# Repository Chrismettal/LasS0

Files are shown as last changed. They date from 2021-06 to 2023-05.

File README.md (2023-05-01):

# LasS0 <!-- omit in toc -->

# Contents <!-- omit in toc -->

- [Buying](#buying)
- [What is this?](#what-is-this)
- [Usage](#usage)
  - [Jumpers:](#jumpers)
- [Firmware](#firmware)
- [Performance](#performance)
  - [New AVR version](#new-avr-version)
    - [0-5V DC pulses, 10Hz, 10ms pulse length](#0-5v-dc-pulses-10hz-10ms-pulse-length)
    - [Shortest stable input pulse - 150ns](#shortest-stable-input-pulse---150ns)
    - [Rise time / delay 100µs](#rise-time--delay-100µs)
    - [5\_10\_i\_r firmware example](#5_10_i_r-firmware-example)
  - [Old S8050 / FET version](#old-s8050--fet-version)
    - [0-5V DC pulses, 50Hz, 5ms pulse length](#0-5v-dc-pulses-50hz-5ms-pulse-length)
    - [Rise time 33µs, Fall time 1µs](#rise-time-33µs-fall-time-1µs)
    - [Switch on delay 66µs](#switch-on-delay-66µs)
    - [Switch off delay 5µs](#switch-off-delay-5µs)
    - [TCRCT5000 with "normal" non inverted configuration](#tcrct5000-with-normal-non-inverted-configuration)
    - [TCRCT5000 with "inverted" configuration](#tcrct5000-with-inverted-configuration)
- [3D printing](#3d-printing)

# Buying

Some leftover boards are stocked at Tindie. More can be manufactured if there is demand:



**If you like my work please consider [supporting my caffeine addiction](https://github.com/Chrismettal#donations)!**

# What is this?

This is a logic level impulse to S0 converter/interface board. It is used to convert 5v logic level impulses to an S0 compatible format to use sensors like the TCRT5000 reflective optical sensor in existing smart home systems, that usually use 12v or 24v levels for digital inputs. This can be used to read out old school electrical meters as well as modern smart meters that only offer optical IR impulses or a spinning disc to "display" the current power usage.

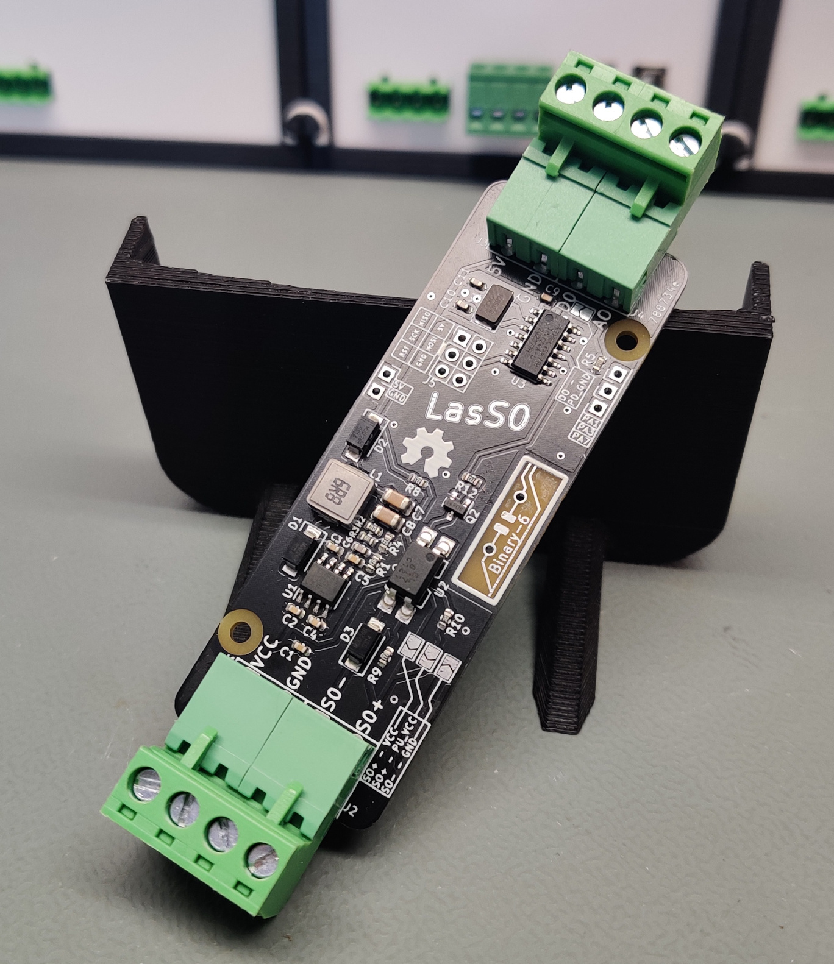
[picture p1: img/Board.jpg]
BoardReal


There are 'two versions' of the board included. LasS0_FET uses a FET input stage. The included gerbers are NOT tested and probably won't be. The initial NPN input stage version however was ordered and tested working.
The other, more recent version uses an AVR microcontroller as the input stage, specifically providing pulse extension and pulse division between the input and the S0 output. This was neccessary for me since my electricity meter outputs 10,000 imp/kWh with only a pulselength of about 7ms, which my smart home controller could not read. It required pulses of at least 15ms to reliably detect every pulse. The AVR counts a set number of input pulses and outputs a fixed output pulse once enough inputs have been counted. In my case I divide 10:1 and output a 30ms pulse after every 10 input pulses, changing the total resolution of my specific meter to 1,000 imp/kwh.

The AVR board additionaly breaks out all unused portpins to pinheaders as well as the AO screw terminal so you could theoretically read out the analog value of a TCRT5000 as well.

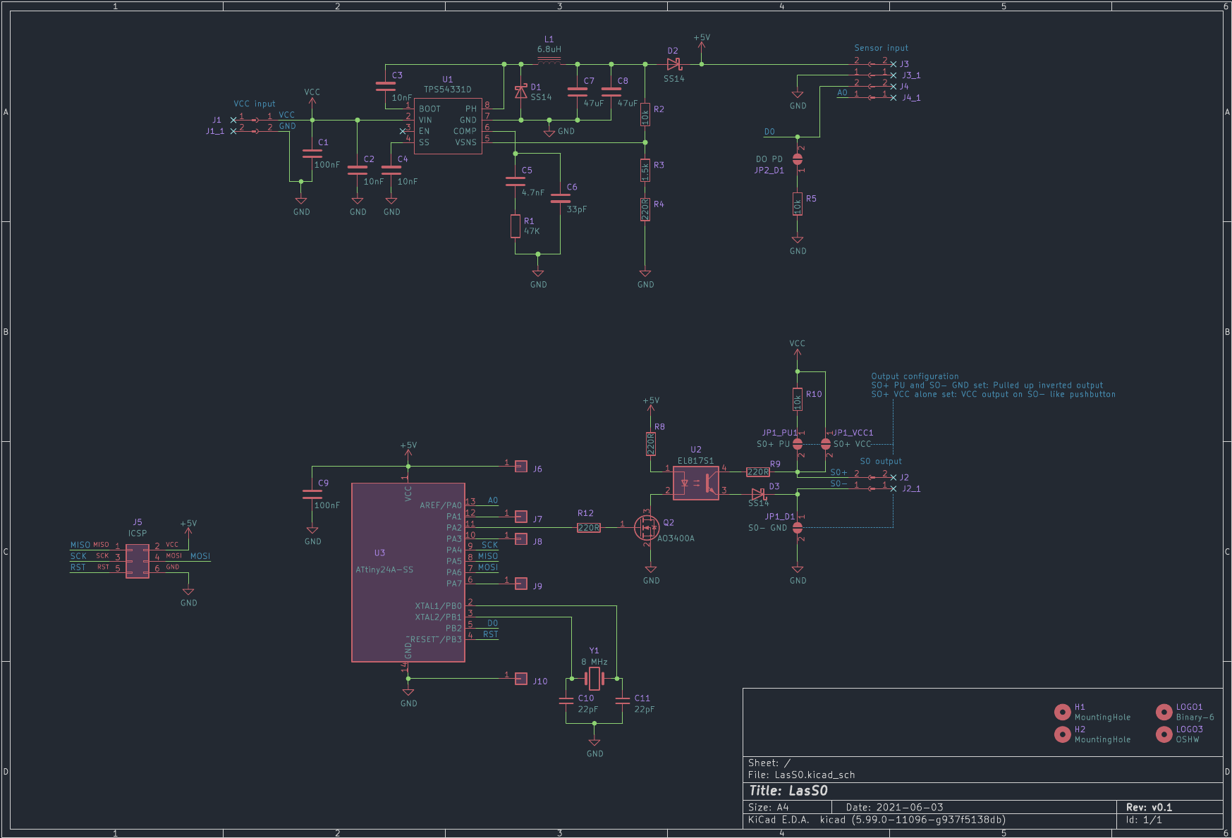
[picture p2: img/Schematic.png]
Schematic


# Usage

The device needs to be powered through `J1` with 12-24v.

One of the upper jumpers needs to be set to choose between `Direct` and `Inverted` which would invert the output fully. If no jumper is set you won't get any output. If both jumpers are set you are going to have a bad time.

A 5v logic level impulse input such as the output of a TCRT5000 can be connected to `J3/J4` at `D0`, which is then output to `J2` as an `S0` compatible open collector signal through the optocoupler.

## Jumpers:

The following jumpers need to be configured to your usecase. Without setting anything, you will get an open S0 output without any pullup/downs on the inputs or outputs.

- `S0+ - VCC` - connects `S0+` to `VCC`, allowing VCC pulses to be output on `S0-`
- `S0+ - PU_VCC` - connects `S0+` to `VCC` via a 10K pullup.
- `S0- - GND` - connects `S0-` to `GND`,  can be used with `S0+ - PU_VCC` to have 24 V logic pulses on `S0+`, which is how I use it for Loxone inputs
- `D0-PD_GND` - connects a 10K pulldown to the D0 input. The AVR only has included pullups on the input port so if your application needs a pulldown it can be enabled on the board. Pullups can be enabled in firmware.

Additionally `PA1`, `PA3`, `PA7` as well as `5V` and `GND` are broken out to pin headers, the `ICSP` port is fully exposed to pin headers, and `PA0` is exposed to the `A0` screw terminal, enabling analog inputs as well.

# Firmware

To translate any type of input pulse to any type of output pulse an Attiny24a is used. The firmware is done in C but built in PlatformIO. The project can be found in the `firmware/Platformio` folder. To compile and upload, you will need to choose one of the build environments as `default` will compile and upload all build configurations one after the other.

If you don't wanna compile yourself, there are several prebuild binaries for different configurations of input and output pulses. Find them in the `firmware/builds` directory.
This directory contains  .elf and .hex files for every environment.

The naming structure for the environments is as follows:

`tinyWW_XXX_Y_Z`

- `W` = Divider ratio
- `X` = Output pulse length
- `Y` = `r` for rising edge input, `f` for falling edge input
- `Z` = `i` for inverted output, `n` for non-inverted output

So:
- `tiny10_30_n_r` generates a `30 ms` `positive` output pulse for every `10` `rising edges` on the input
- `tiny5_250_i_f` generates a `250ms` `negative` output pulse for every `5` `falling edges` on the input

The firmware is uploaded via `ICSP`.

# Performance

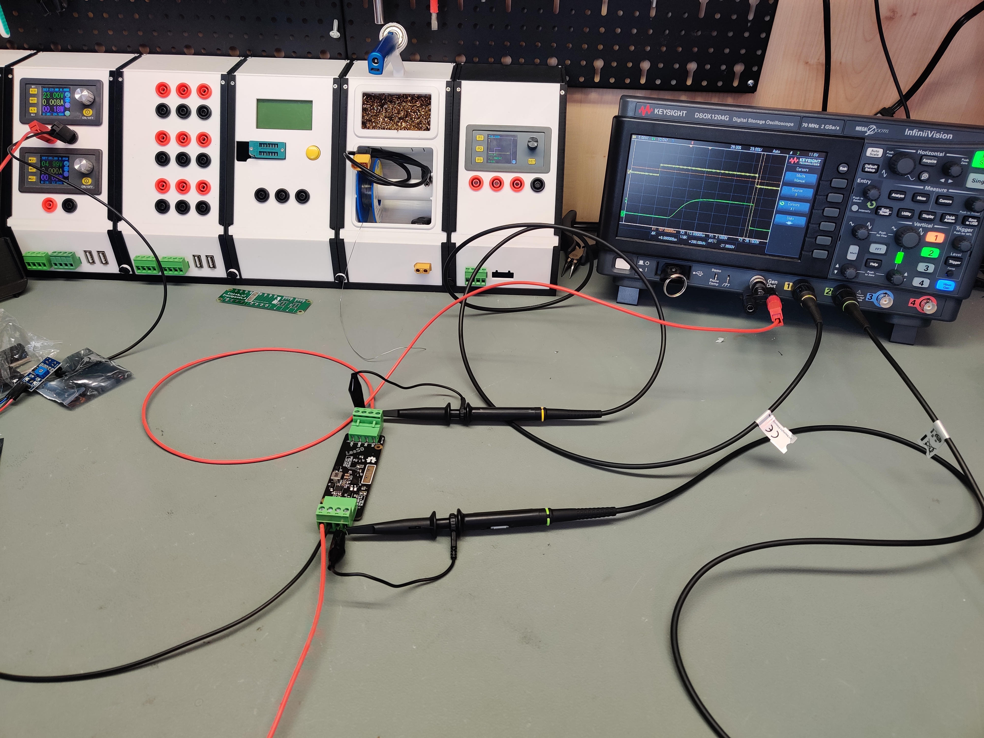
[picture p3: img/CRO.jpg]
MeasurementMethod


The device was tested, on a 23 V supply with 5 V test pulses from a function gen as well as the TCRT5000.
## New AVR version

This version uses the high input impedance of the ATTINY inputs, reducing required input current significantly, not loading your input sensor at all. The following measurements / demonstrations were done with the `AVR` board, PCB version 788734e, with the `S0+ - PU_VCC` and `S0- - GND` jumpers set, setting a pullup to `SO+` and connecting `S0-` to ground. `Channel 1` is the function gen output, `Channel 2` is measuring the pulled up `S0+`. 

The firmware version used is 1_10_n_r, outputting a 10ms non-inverted output pulse for every rising edge on the input.

### 0-5V DC pulses, 10Hz, 10ms pulse length

10ms input pulses being translated to 10ms output pulses, just shifting levels.

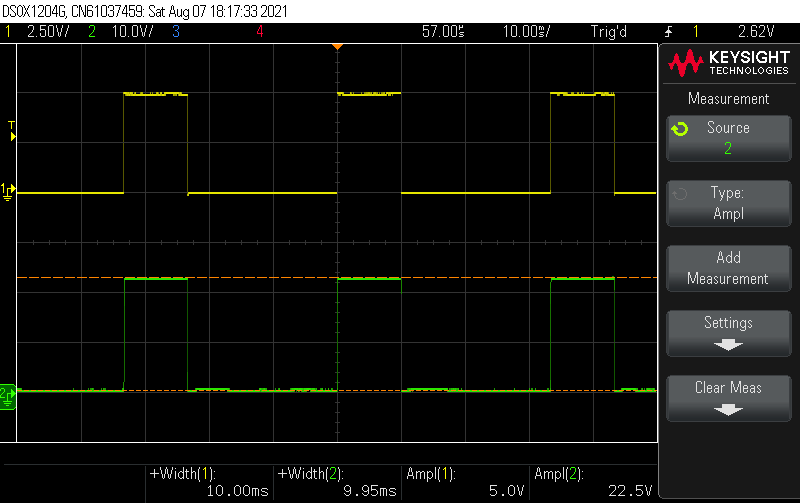
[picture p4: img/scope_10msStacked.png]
10msStacked


### Shortest stable input pulse - 150ns

The shortest input pulse that is stable to detect is about 150ns long at 5V. The device still outputs a 10ms output pulse.

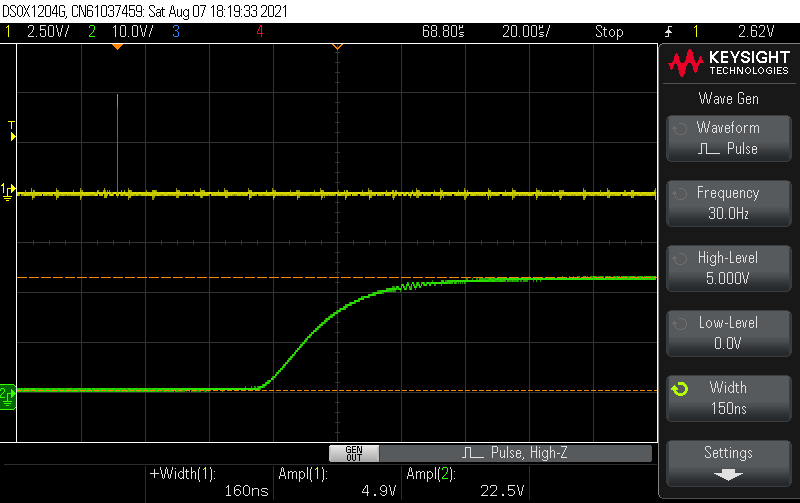
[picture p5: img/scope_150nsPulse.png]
150nsPulse


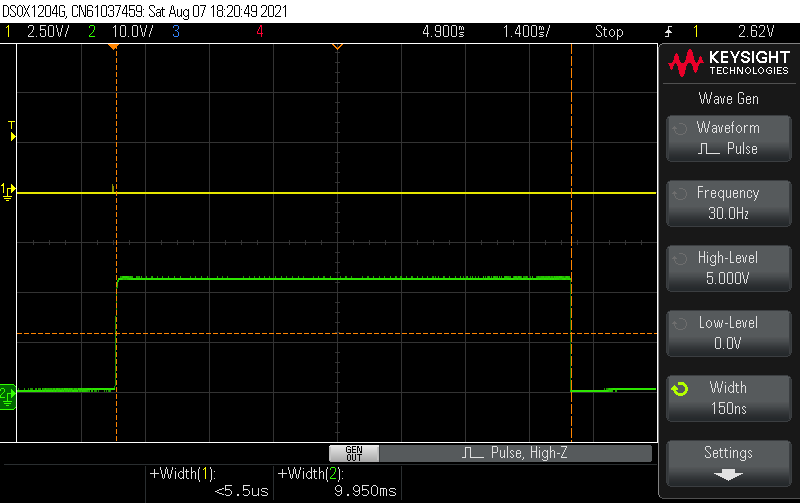
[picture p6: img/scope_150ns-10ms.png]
150ns10ms


### Rise time / delay 100µs

Looking only at the switch on time the device needs about 100µs to fully switch on the output after detecting a rising edge on the input.

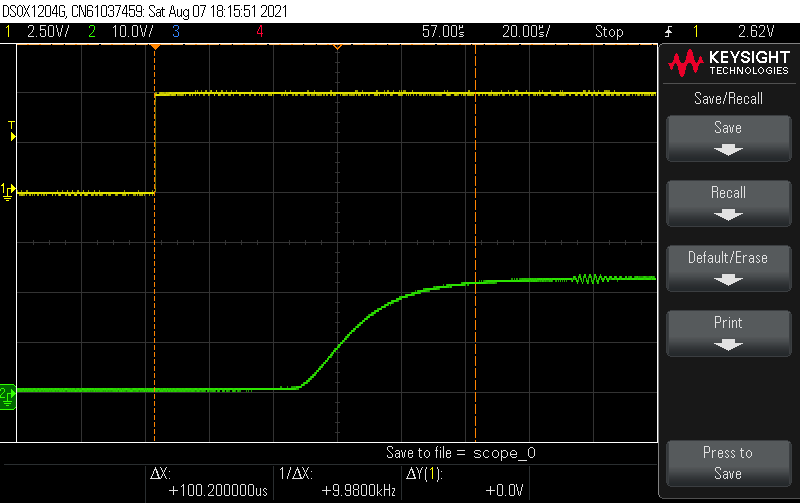
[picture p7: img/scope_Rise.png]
Rise100


### 5_10_i_r firmware example

The following screenshot is a demonstration of the 5_10_i_r firmware, outputting a 10ms inverted output pulse for every 5 edges on the input.

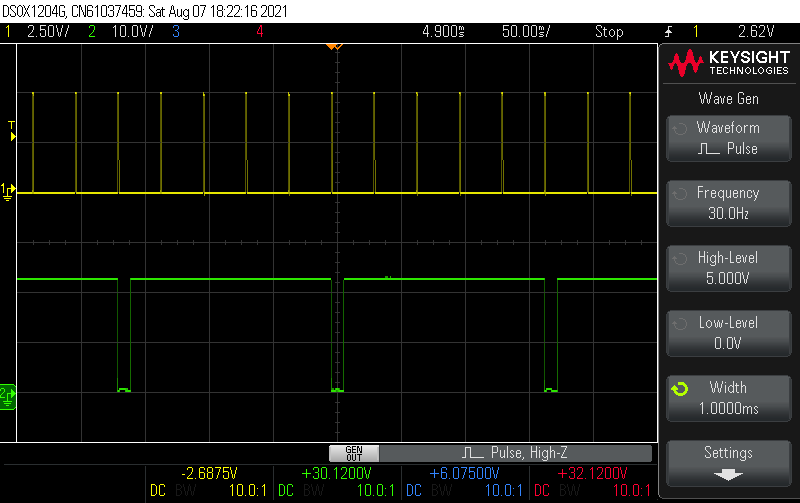
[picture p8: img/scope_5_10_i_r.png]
5_10_i_r


## Old S8050 / FET version

The version that was tested needs around 6mA of current on the DO input to drive the input stage. My TCRT5000 module is only able to deliver about 1mA somehow so the channel 1 voltage with the TCRT5000 drops significantly but the output is still fully driven. Currently ordering some new TCRT5000 to see why the comparator can only drive such low currents. 

The same measurements have been done with the FET version using AO34000A MOSFETs, removing the high input current but otherwise providing almost identical outputs (mostly limited by the output optocoupler, which explains the similar results).

The following measurements / demonstrations were done with the S8050 input stage, PCB revision 38b7723, with the S0 pullup jumpers set:

### 0-5V DC pulses, 50Hz, 5ms pulse length

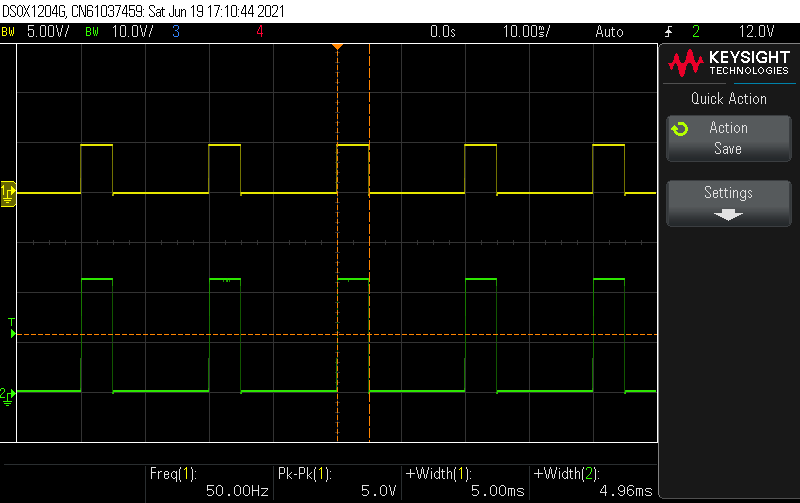
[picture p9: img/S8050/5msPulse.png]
5msPulse


### Rise time 33µs, Fall time 1µs

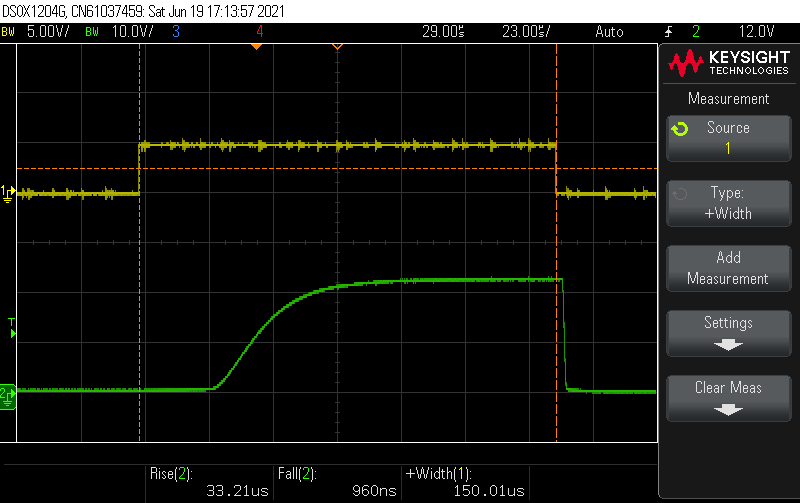
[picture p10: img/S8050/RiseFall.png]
RiseFall


### Switch on delay 66µs

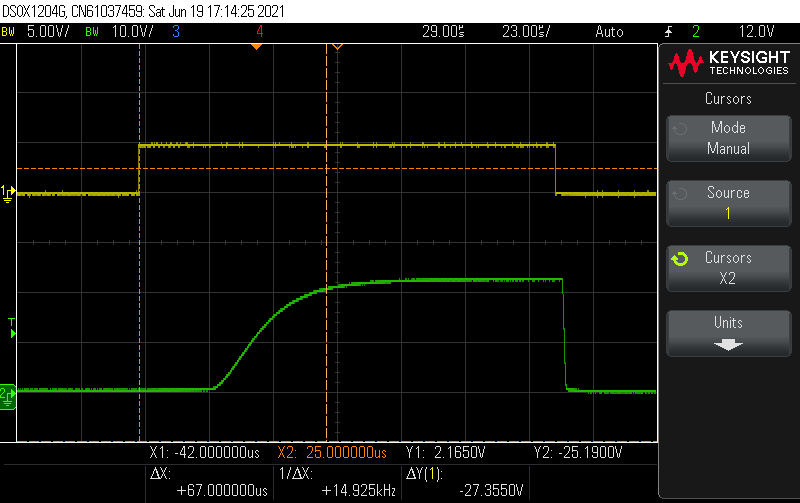
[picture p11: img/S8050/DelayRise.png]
DelayRise


### Switch off delay 5µs

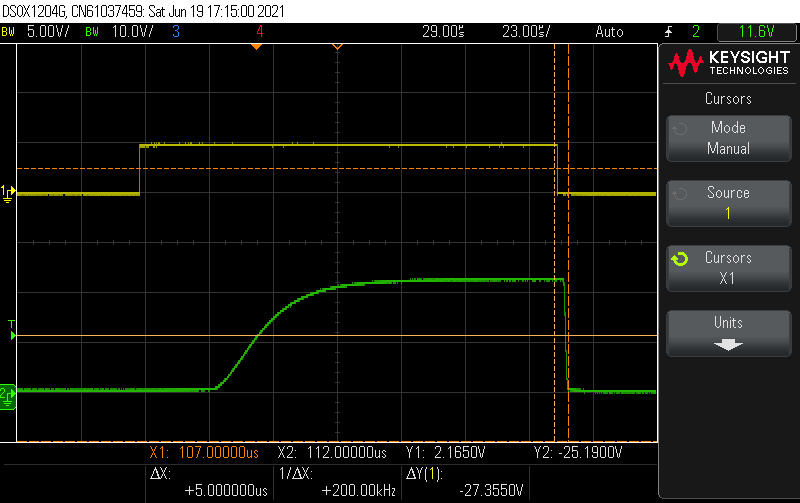
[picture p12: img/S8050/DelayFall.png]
DelayFall


### TCRCT5000 with "normal" non inverted configuration

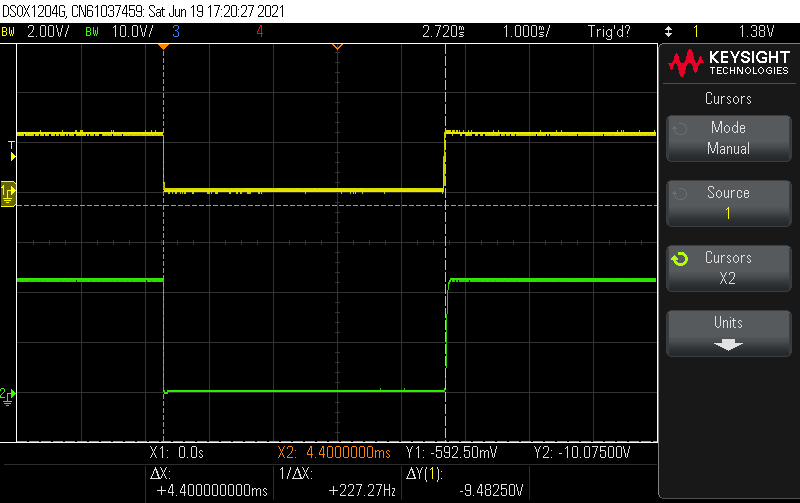
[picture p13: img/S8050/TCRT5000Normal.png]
Normal


### TCRCT5000 with "inverted" configuration

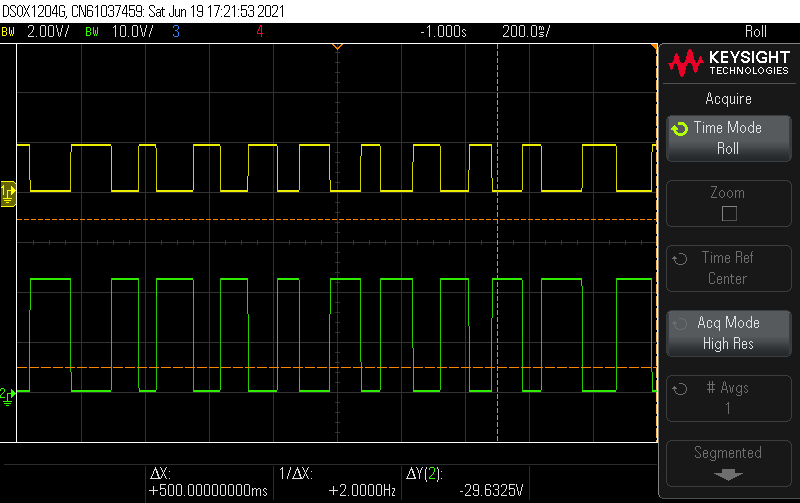
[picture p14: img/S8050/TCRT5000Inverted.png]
Inverted


# 3D printing

Considering this is meant to go inside your electrical cabinet it is best printed in PC or ABS and not PLA.

There is a 3D printable DIN rail case for the LasS0 PCB itself, as well as a readhead to attach a TCRT5000 module to EMH eHZ readers (which is what I am using this whole project for).

The case incorporates DIN rail clamps, remixed from a cable clamp by mdkendall, [check it out here!](https://www.thingiverse.com/thing:2613804).

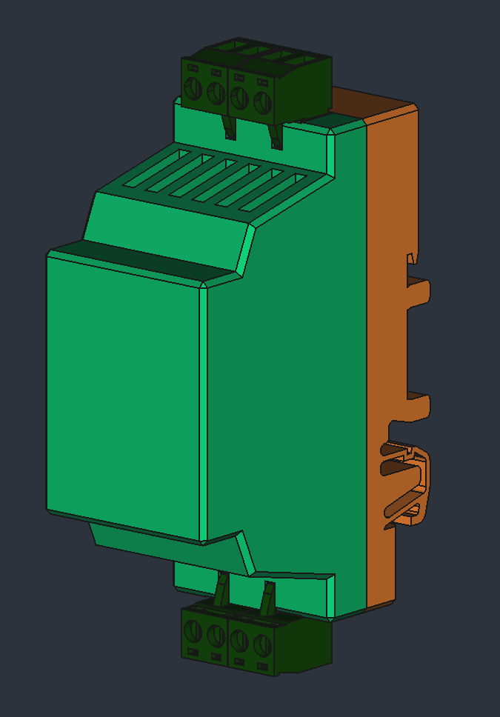
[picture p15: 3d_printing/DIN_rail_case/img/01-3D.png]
3DCase


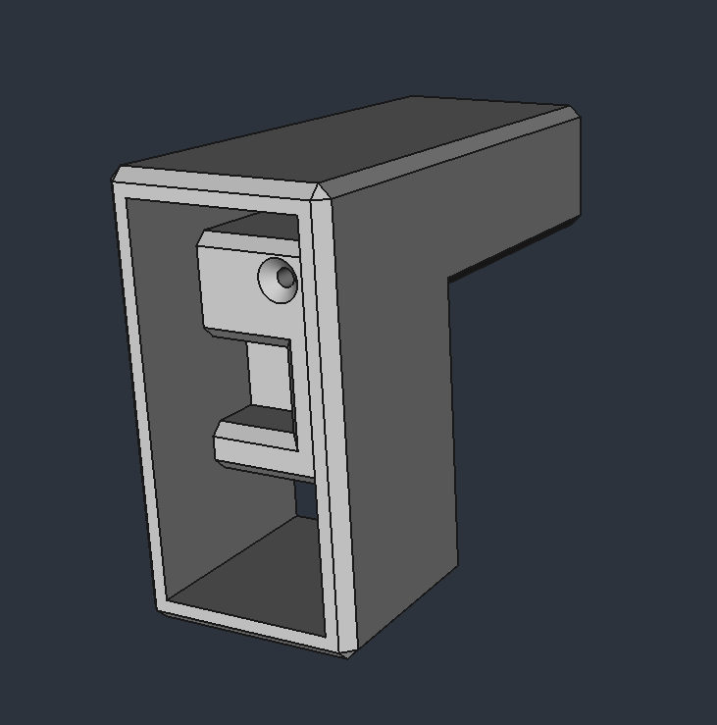
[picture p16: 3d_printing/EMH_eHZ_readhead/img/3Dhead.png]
3DHead


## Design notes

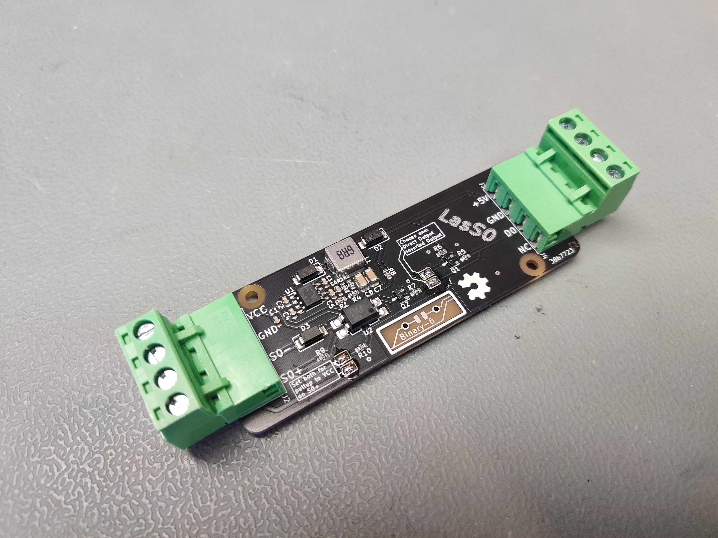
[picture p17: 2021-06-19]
img/S8050/Board.jpg

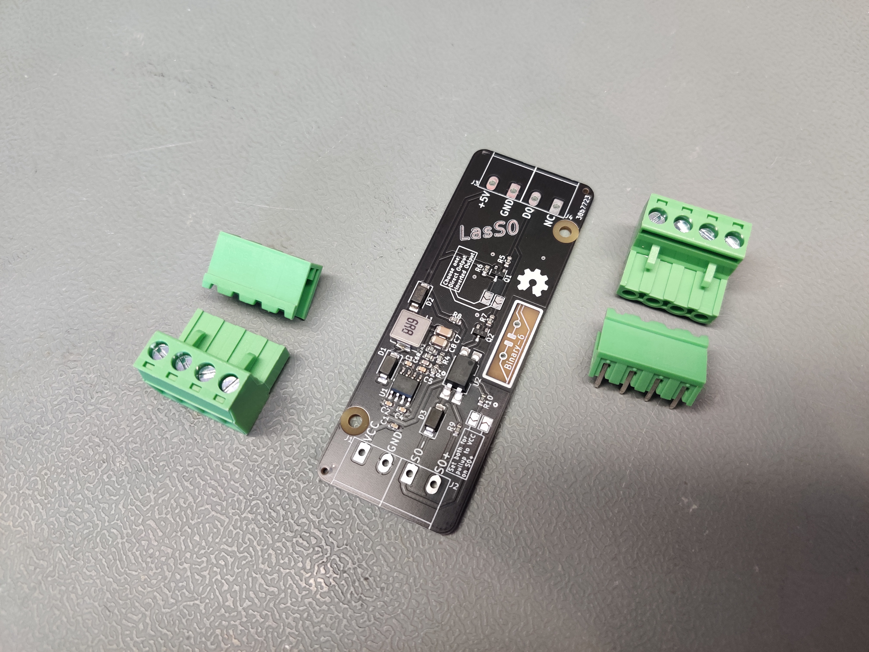
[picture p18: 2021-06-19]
img/S8050/BoardKit.jpg

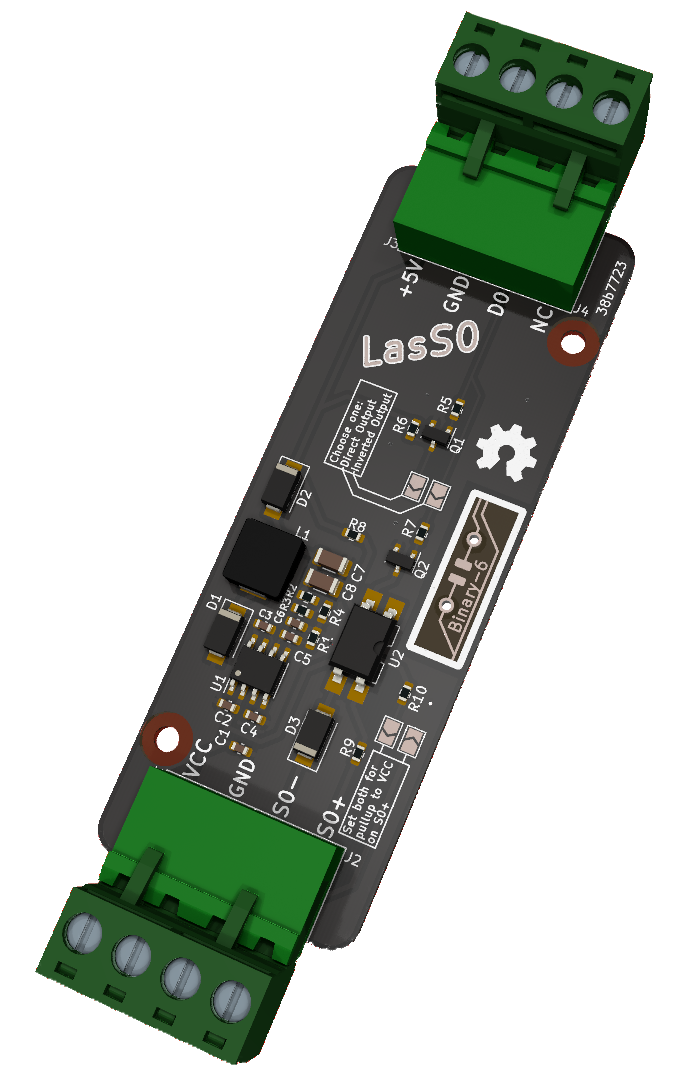
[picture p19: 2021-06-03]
img/S8050/Nice.png

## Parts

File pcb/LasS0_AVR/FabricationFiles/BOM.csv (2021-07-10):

Comment | Designator | Footprint | LCSC
100nF | C1,C9 | Capacitor_SMD:C_0603_1608Metric | C14663
22pF | C10,C11 | Capacitor_SMD:C_0603_1608Metric | C1653
10nF | C2,C3,C4 | Capacitor_SMD:C_0603_1608Metric | C57112
4.7nF | C5 | Capacitor_SMD:C_0603_1608Metric | C53987
33pF | C6 | Capacitor_SMD:C_0603_1608Metric | C1663
47uF | C7,C8 | Capacitor_SMD:C_1206_3216Metric | C96123
SS14 | D1,D2,D3 | Diode_SMD:D_SMA | C2480
CiKe2PinSock | J1,J2,J3,J4 | MeineBib:Cixi_Kefa_Elec_KF2EDGR-5.08-2P | C8383
6.8uH | L1 | MeineBib:Sunltech_SLO0630H | C207841
AO3400A | Q2 | Package_TO_SOT_SMD:SOT-23 | C693097
47K | R1 | Resistor_SMD:R_0603_1608Metric | C25819
10k | R2,R5,R10 | Resistor_SMD:R_0603_1608Metric | C25804
1.5k | R3 | Resistor_SMD:R_0603_1608Metric | C22843
220R | R4,R8,R9,R12 | Resistor_SMD:R_0603_1608Metric | C22962
TPS54331D | U1 | Package_SO:SOIC-8_3.9x4.9mm_P1.27mm | C9865
EL817S1 | U2 | Package_DIP:SMDIP-4_W9.53mm | C106900
ATtiny24A-SS | U3 | Package_SO:SOIC-14_3.9x8.7mm_P1.27mm | C14909
8 MHz | Y1 | Crystal:Crystal_SMD_5032-2Pin_5.0x3.2mm | C115962

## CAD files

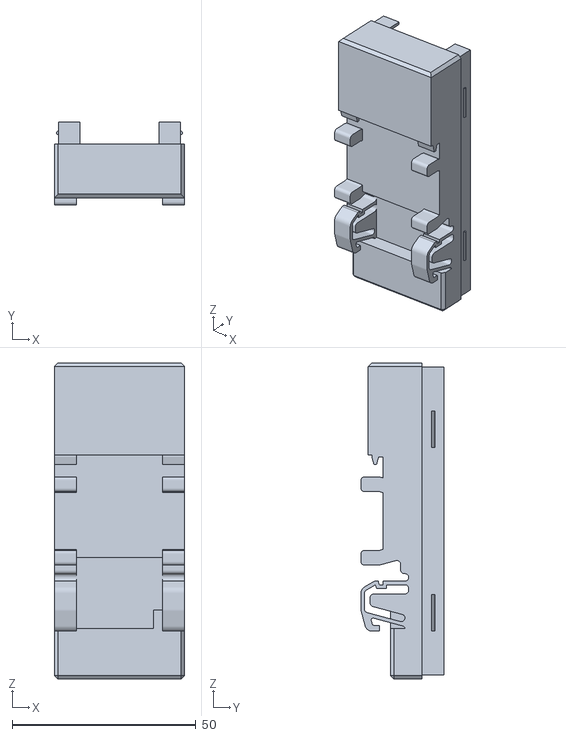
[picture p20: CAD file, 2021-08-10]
3d_printing/DIN_rail_case/3d/LasS0-Lower.stl
35.5 x 22.6 x 86.0

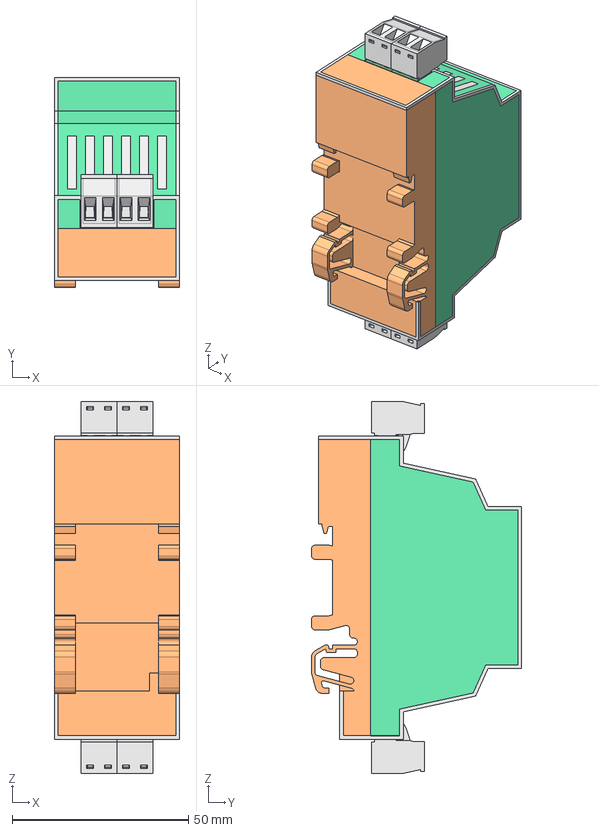
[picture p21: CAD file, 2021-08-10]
3d_printing/DIN_rail_case/source/LasS0.FCStd
35.5 x 59.5 x 105.4 mm
LoxBody
Upper
Lower

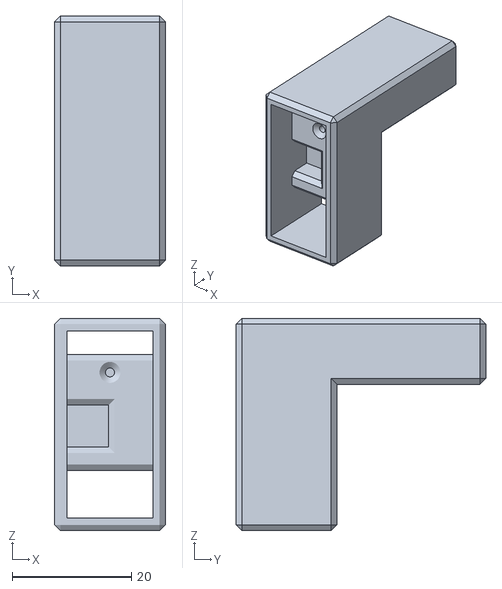
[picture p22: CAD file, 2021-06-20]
3d_printing/EMH_eHZ_readhead/3d/EMH_eHZ_readhead-PartBody.stl
18.7 x 42.0 x 35.7

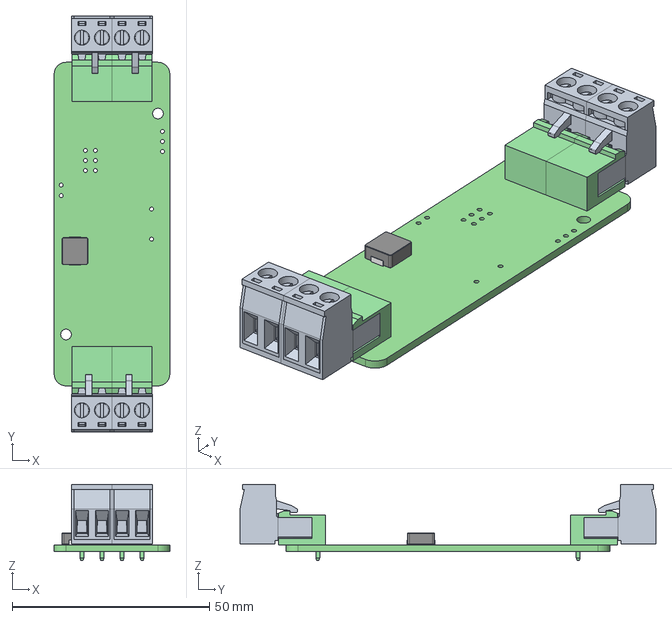
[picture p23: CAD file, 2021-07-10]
pcb/LasS0_AVR/3D/LasS0.step
29.3 x 105.4 x 19.3 mm

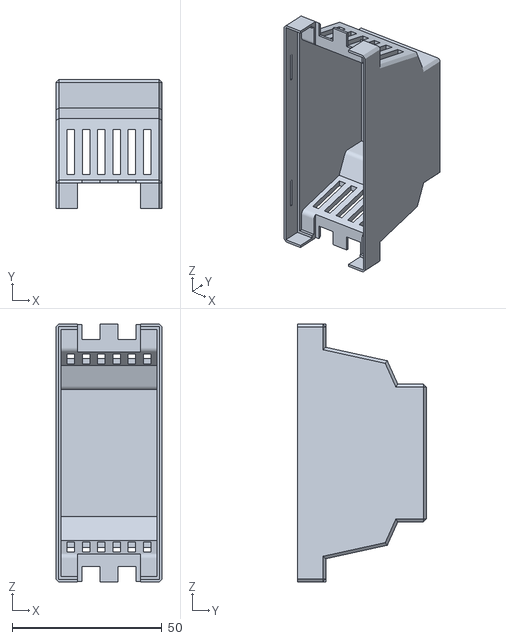
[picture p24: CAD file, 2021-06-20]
3d_printing/DIN_rail_case/3d/LasS0-Upper.stl
35.5 x 42.8 x 86.0

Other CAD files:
3d_printing/EMH_eHZ_readhead/source/EMH_eHZ_readhead.FCStd

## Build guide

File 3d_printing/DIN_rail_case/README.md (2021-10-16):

Autodeploy

It's time for change

Behold, for once again, change is upon us!

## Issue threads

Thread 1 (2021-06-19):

6mA driving current for DO input seems to high for some sensors

Chrismettal, 2021-06-19:
On the 5V DO input side LasS0 needs around 6mA driving current to switch die S8050s, which at least one of my TCRT5000 modules can't provide. Will try switching the input stage to AO3400A MOSFETS instead of NPN transistors to raise input impedance.

Chrismettal, 2021-06-20:
Swapped out the S8050 input stage for AO3400A MOSFETs which greatly raised input impedance. TCRT5000 sensors no longer cry when driving LasS0.

I would not want to leave the input stage without a pulldown for FETs, but since the TCRT5000 modules already use pullups on their output, a fixed pulldown would not be viable, so the PCB update will get optional pullups and downs on the input stage.

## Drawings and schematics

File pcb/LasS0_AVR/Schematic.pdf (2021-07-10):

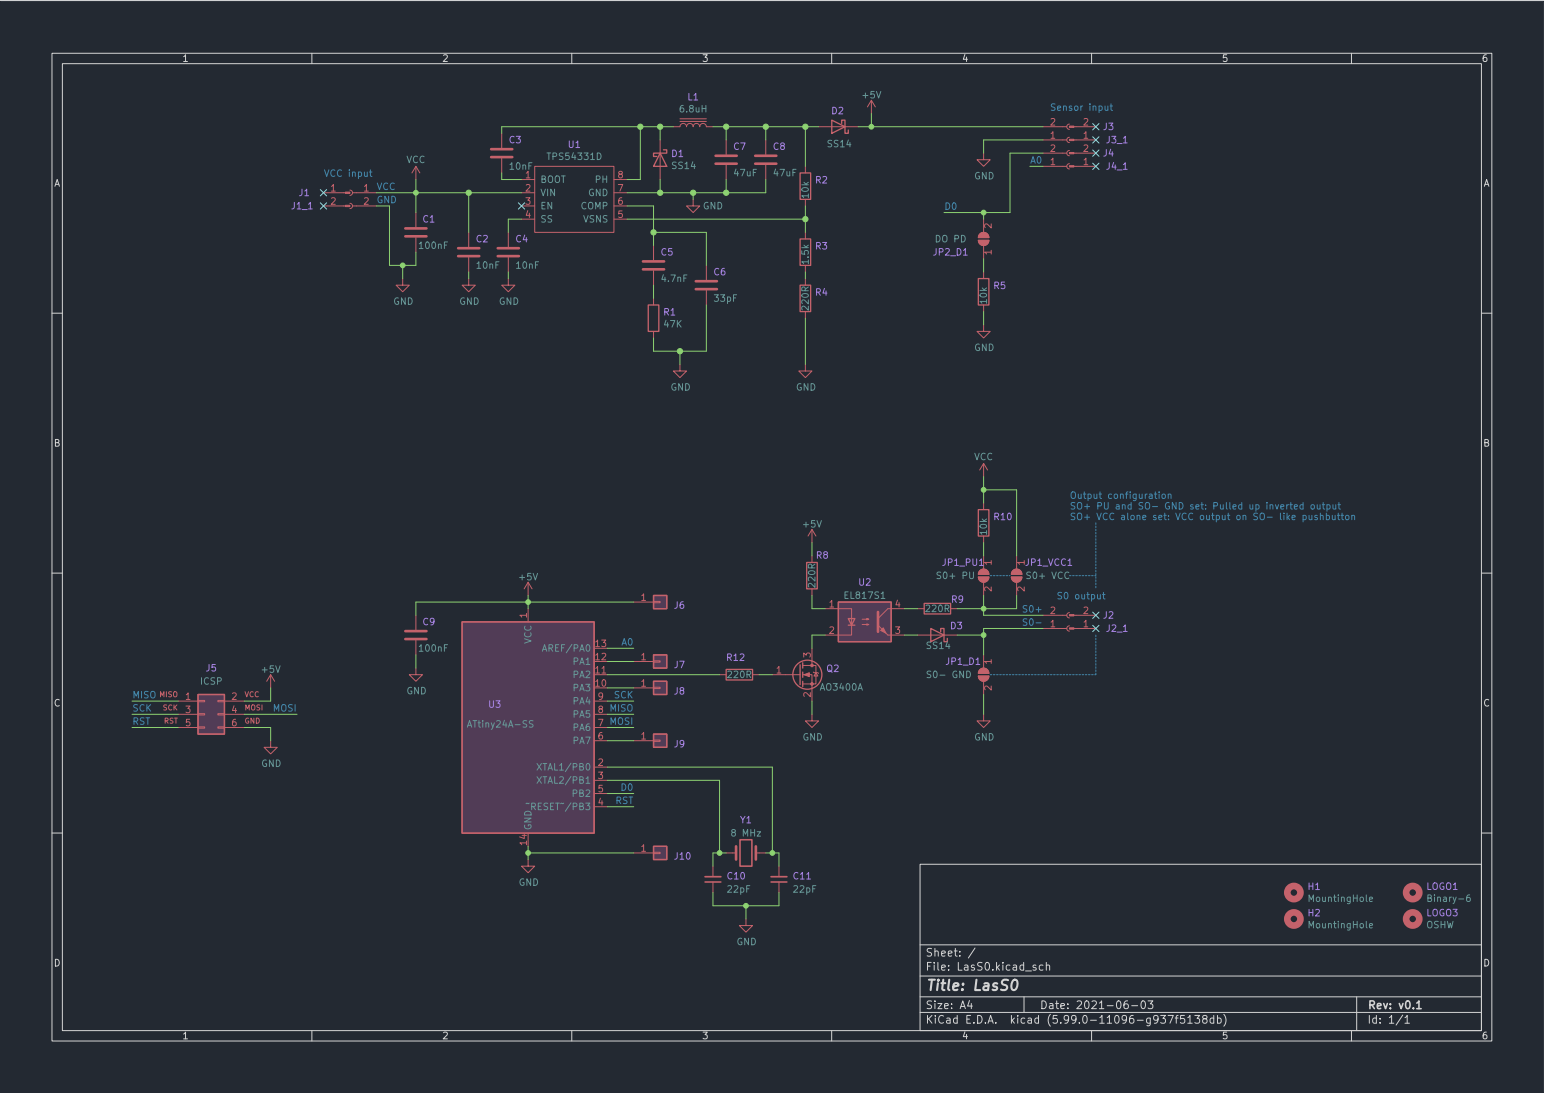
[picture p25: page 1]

Output configuration
SO+ PU and SO- GND set: Pulled up inverted output
SO+ VCC alone set: VCC output on SO- like pushbutton

1 PA3 10 PA2 11 PA1 12 AREF/PA0 13 GND 14 XTAL1/PB0 2 XTAL2/PB1 3 ~RESET~/PB34 PB2 5 PA7 6 PA6 7 PA5 8 PA4 9 U3 ATtiny24A-SS

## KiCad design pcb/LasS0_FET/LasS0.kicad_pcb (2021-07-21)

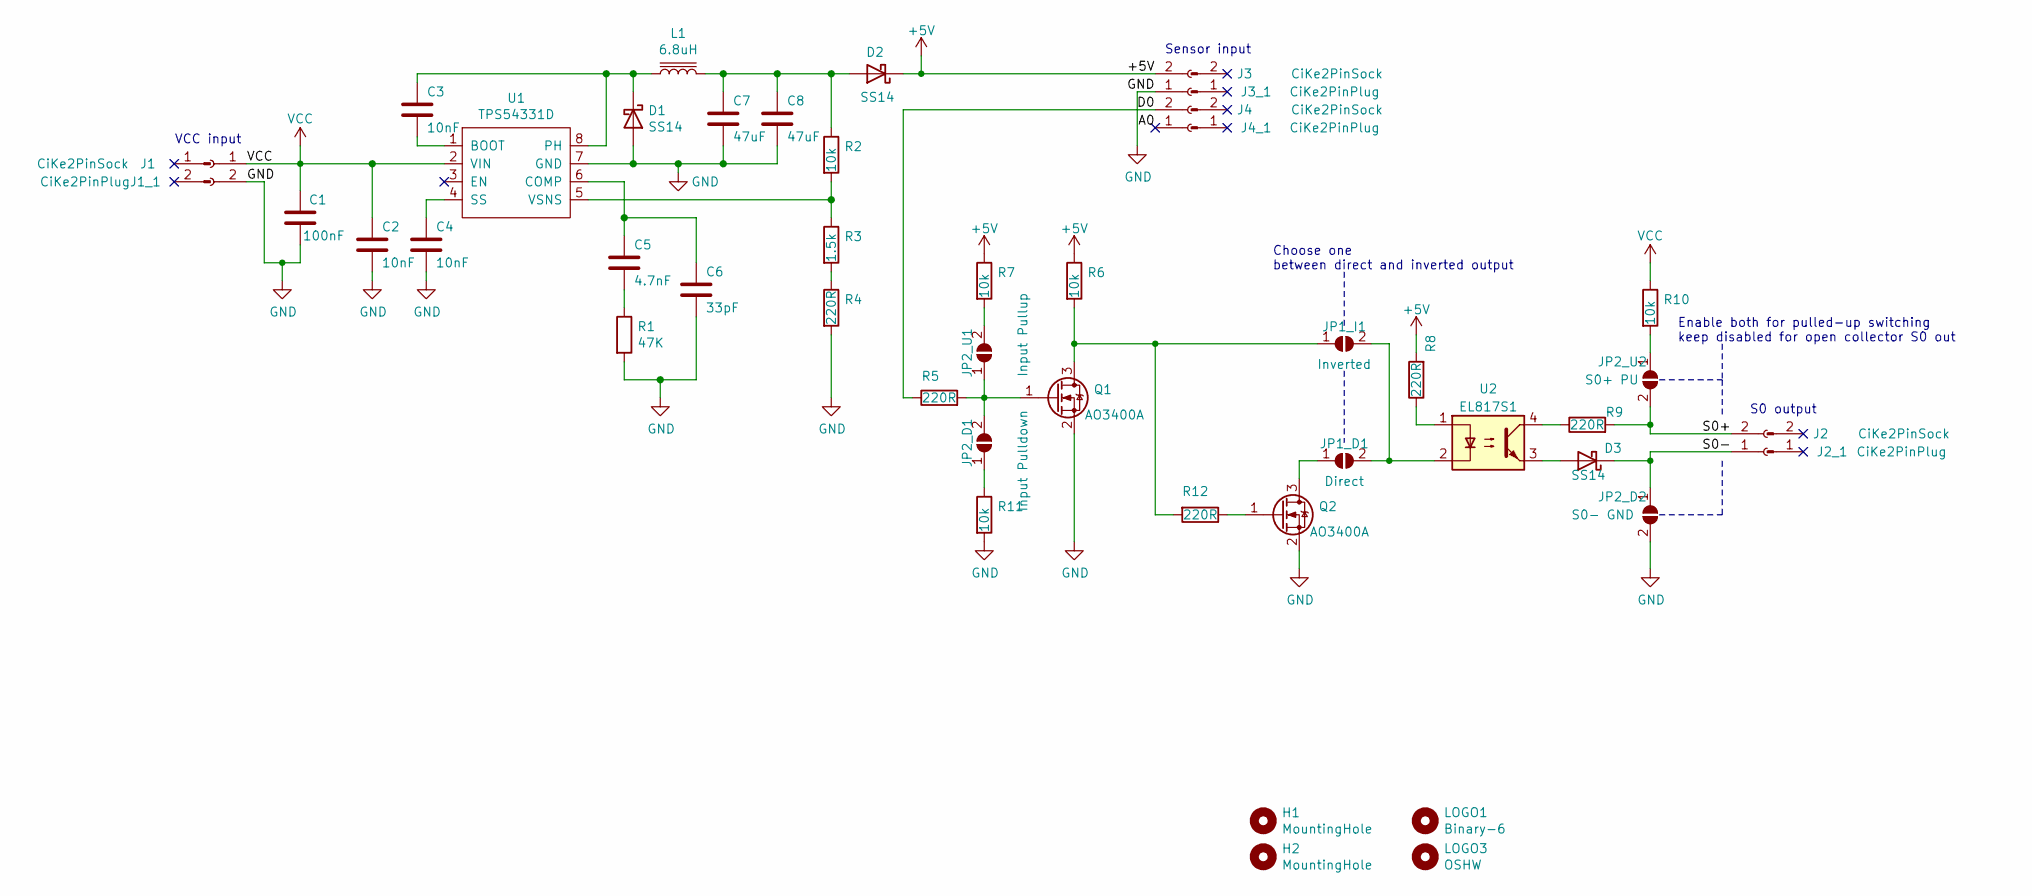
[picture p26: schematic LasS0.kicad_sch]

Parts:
C1: 100nF; C_0603_1608Metric; LCSC C14663
C2, C3, C4: 10nF; C_0603_1608Metric; LCSC C57112
C5: 4.7nF; C_0603_1608Metric; LCSC C53987
C6: 33pF; C_0603_1608Metric; LCSC C1663
C7, C8: 47uF; C_1206_3216Metric; LCSC C96123
D1, D2, D3: SS14; D_SMA; LCSC C2480
H1, H2: MountingHole; EigenesMountingHole_2.7mm_M2.5
J1, J2, J3, J4: CiKe2PinSock; Cixi_Kefa_Elec_KF2EDGR-5.08-2P; LCSC C8383
J1_1, J2_1, J3_1, J4_1: CiKe2PinPlug; LCSC C71370
JP1_D1: Direct; SolderJumper-2_P1.3mm_Open_TrianglePad1.0x1.5mm
JP1_I1: Inverted; SolderJumper-2_P1.3mm_Open_TrianglePad1.0x1.5mm
JP2_D1: Input Pulldown; SolderJumper-2_P1.3mm_Open_TrianglePad1.0x1.5mm
JP2_D2: S0- GND; SolderJumper-2_P1.3mm_Open_TrianglePad1.0x1.5mm
JP2_U1: Input Pullup; SolderJumper-2_P1.3mm_Open_TrianglePad1.0x1.5mm
JP2_U2: S0+ PU; SolderJumper-2_P1.3mm_Open_TrianglePad1.0x1.5mm
L1: 6.8uH; Sunltech_SLO0630H; LCSC C207841
LOGO1: Binary-6; Binary_6_v0.1
LOGO3: OSHW; OSHW-Symbol_6.7x6mm_SilkScreen
Q1, Q2: AO3400A; SOT-23; LCSC C693097
R1: 47K; R_0603_1608Metric; LCSC C25819
R2, R6, R7, R10, R11: 10k; R_0603_1608Metric; LCSC C25804
R3: 1.5k; R_0603_1608Metric; LCSC C22843
R4, R5, R8, R9, R12: 220R; R_0603_1608Metric; LCSC C22962
U1: TPS54331D; SOIC-8_3.9x4.9mm_P1.27mm; LCSC C9865
U2: EL817S1; SMDIP-4_W9.53mm; LCSC C106900

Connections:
+5V: D2.1 (K), J3.2, R6.1, R7.1, R8.2
/A0: J4.1
/D0: J4.2, R5.1
/S0+: J2.2, JP2_U2.2 (B), R9.2
/S0-: D3.1 (K), J2.1, JP2_D2.1 (A)
GND: C1.1, C2.2, C4.2, C6.2, C7.2, C8.2, D1.2 (A), J1.2, J3.1, JP2_D2.2 (B), Q1.2 (S), Q2.2 (S), R1.2, R4.2, R11.2, U1.7 (GND)
unnamed: C3.1, D1.1 (K), L1.2, U1.8 (PH)
unnamed: C3.2, U1.1 (BOOT)
unnamed: C4.1, U1.4 (SS)
unnamed: C5.1, C6.1, U1.6 (COMP)
unnamed: C5.2, R1.1
unnamed: C7.1, C8.1, D2.2 (A), L1.1, R2.1
unnamed: D3.2 (A), U2.3
unnamed: JP1_D1.1 (A), Q2.3 (D)
unnamed: JP2_D1.1 (A), R11.1
unnamed: JP2_D1.2 (B), JP2_U1.1 (A), Q1.1 (G), R5.2
unnamed: JP2_U1.2 (B), R7.2
unnamed: JP2_U2.1 (A), R10.2
unnamed: Q2.1 (G), R12.1
unnamed: R2.2, R3.1, U1.5 (VSNS)
unnamed: R3.2, R4.1
unnamed: JP1_I1.1 (A), Q1.3 (D), R6.2, R12.2
unnamed: R8.1, U2.1
unnamed: R9.1, U2.4
unnamed: JP1_D1.2 (B), JP1_I1.2 (B), U2.2
VCC: C1.2, C2.1, J1.1, R10.1, U1.2 (VIN)

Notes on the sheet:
VCC input
Sensor input
Choose one between direct and inverted output
Enable both for pulled-up switching keep disabled for open collector S0 out
S0 output

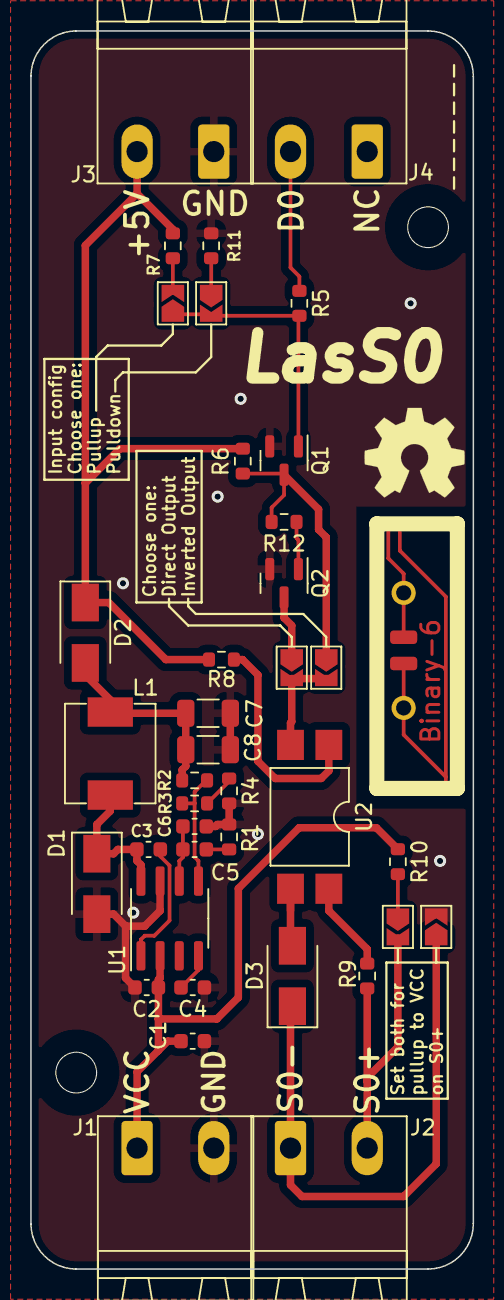
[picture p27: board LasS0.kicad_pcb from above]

Board: 2 copper layers, 29.3 x 82.0 mm, 42 parts (0 on the bottom side), 25 nets.

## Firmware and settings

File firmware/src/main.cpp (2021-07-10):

/*--------------------------------------------------------------------------------------------------------------------------------------*/
/*------------------------------------------------------------Pulse Extender------------------------------------------------------------*/
/*--------------------------------------------------------------------------------------------------------------------------------------*/
/*  
 * Reads short input pulses <= 10ms and outputs longer output pulses of ~ 30ms.
 * Input pulses are counted and divided to account for lower maximum frequency of output pulses.
 * 
 * Used to convert 7ms long IR LED pulses from a EMH eHZ via an TCRT5000 read head to 30ms S0 pulses.
 * EMH eHZ delivers 10.000 imp/kWh, after conversion we get 1000 imp/kwh 
 */

/*-------------------------------------------------------------------*/
/*--------------------------Includes---------------------------------*/
/*-------------------------------------------------------------------*/

#include <avr/io.h>
#include <avr/interrupt.h>

/*-------------------------------------------------------------------*/
/*--------------------------Settings---------------------------------*/
/*-------------------------------------------------------------------*/

/* defined via PlatformIO environment build flags
#define DIVIDER_RATIO               1           // Divider ratio between input pulses and output pulses
#define OUTPUT_PULSE_LENGTH_mS      30          // Output pulse length in milliseconds, max 500ms
#define NORMAL_OUTPUT                           // normal output if set, inverted if unset
#define RISING_EDGE_INPUT                       // Rising edge input if set, falling if unset
*/
// Attiny24a Pins
#define PIN_INPUT                   2           // PORTPIN of port B for input pulse
#define PIN_OUTPUT                  2           // PORTPIN of port A for output pulse


/*-------------------------------------------------------------------*/
/*-----------------------------Vars----------------------------------*/
/*-------------------------------------------------------------------*/

volatile uint8_t  EdgesFound;                   // Number of edges found since last flush (EdgesFound >= DIVIDER_RATIO)
bool              Output;                       // Output buffer to be shoved into the portpin

/*-------------------------------------------------------------------*/
/*------------------------------ISR----------------------------------*/
/*-------------------------------------------------------------------*/

//----------External interrupt 0----------
ISR (INT0_vect){
  EdgesFound++;
}

/*-------------------------------------------------------------------*/
/*-----------------------------Init----------------------------------*/
/*-------------------------------------------------------------------*/
int main() {
  //----------Port Settings----------
  // PORT A
  DDRA  = (1 << PIN_OUTPUT);  // 1 = Output
  // PORT B
//DDRB  = (0 << PIN_INPUT);   // 0 = Input, not required to set
//PORTB = (1 << PIN_INPUT);   // Pullup, optional, not needed in my case

  //--------Timer settings---------
  /*
  F_Timer   = F_CPU / Prescaler
  F_Timer   = 8 MHz / 64      = 125 KHz
  T_Tick    = 1 s / 125 KHz   = 8 µs
  T_Max     = 8 µs X 65536   = 0.524 288 s

  Example OCR1A value:
  30ms / 8 µs = 3750 ticks
  */

  TCCR1B  |= (1 << CS10) | (1 << CS11);       // set clock source /64 prescaler, starting timer
  OCR1A    = OUTPUT_PULSE_LENGTH_mS / 0.008;  // set compare window to number of timer ticks required to hit OUTPUT_PULSE_LENGTH_mS

  //--------Interrupt attach---------
  GIMSK   |= (1 << INT0);                     // enable INT0 mask

  // switch between rising and falling edge input
  #ifdef RISING_EDGE_INPUT
    MCUCR   |= (1 << ISC00) | (1 << ISC01);   // enable INT0 rising edge detection
  #else
    MCUCR   |= (1 << ISC01);                  // enable INT0 falling edge detection
  #endif

  sei();                                      // enable all interrupts

/*-------------------------------------------------------------------*/
/*----------------------------while(1)-------------------------------*/
/*-------------------------------------------------------------------*/
  while(1){
    // if enough pulses are found when timer flag is HIGH (Timer not already running)
    if ((TIFR1 & (1 << OCF1A)) && (EdgesFound >= DIVIDER_RATIO)) {
      EdgesFound      = 0;
      
      TCNT1           = 0;    // reset timer value
      TIFR1 |= (1 << OCF1A);  // clear timer elapsed flag and therefore set S0 output
    }

    //Output TimerElapsedFlag via a buffer. Will generate a single pulse at bootup until timer is elapsed once,
    //but as long as the bit stays HIGH until we clear it manually, we should only output a pulse while timer is running and the flag is low
    Output = (TIFR1 & (1 << OCF1A));

    // switch between normal and inverted output
    #ifdef NORMAL_OUTPUT
      PORTA =  ( Output << PIN_OUTPUT);
    #else
      PORTA =  (!Output << PIN_OUTPUT);
    #endif

  }// end while(1)
}// end main

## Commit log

2021-06-03 Add empty KiCAD project
2021-06-03 Create initial schematic
    [LasS0.kicad_sch]
2021-06-03 Start PCB, add mechanicals
    [LasS0.kicad_pcb, LasS0.kicad_sch]
2021-06-03 Route PCB initial version
    [LasS0.kicad_pcb]
2021-06-03 Prettify PCB
    [LasS0.kicad_pcb]
2021-06-03 Clear up DRC fails
    [LasS0.kicad_pcb]
2021-06-03 Minor cleanup and add JLC number
    [LasS0.kicad_pcb]
2021-06-03 Add version hash to silkscreen
    [LasS0.kicad_pcb]
2021-06-03 Update version hash
    [LasS0.kicad_pcb]
2021-06-03 Create first version fabrication files
    [LasS0.kicad_pcb]
2021-06-03 Add nice picture
    [BOM.csv, Placemap.csv]
2021-06-04 Add initial FreeCAD project
    [LasS0.FCStd]
2021-06-10 Add simulation case to FreeCAD file
    [LasS0.FCStd]
2021-06-10 Work on case
    [LasS0.FCStd]
2021-06-19 Update readme with measurements of first PCB rev
2021-06-19 Try cloning the body to create upper and lower half
    [LasS0.FCStd]
2021-06-19 Add initial version of case for DIN rail and add Prusa MK3s GCode
    [LasS0-Lower.stl, LasS0-Upper.stl, LasS0.FCStd]
2021-06-19 Add picture of 3D case to README
2021-06-20 Add schematic render of 8050 version
2021-06-20 Make holes for terminal plugs wider to accomodate 2 and 4 pin headers
    [LasS0-Upper.stl, LasS0.FCStd]
2021-06-20 Sort 3DPrinting folder, add readhead body
    [EMH_eHZ_readhead-PartBody.stl, EMH_eHZ_readhead.FCStd, LasS0-Lower.stl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]
2021-06-20 Update readme with 3d printing information
2021-06-20 Update PCB:
    - Switch to MOSFET input stage
    - Add optional pullups/pulldowns on DO input
    - Sadly make LOGO less pretty
    Fabrication files are NOT updated yet, PCB version number is NOT updated yet
    [LasS0.kicad_pcb, LasS0.kicad_sch]
2021-06-20 Remove all PCB fabrication outputs, until enough tests with MOSFET input stage are done
    [BOM.csv, Placemap.csv]
2021-06-20 Also delete 3D files from PCB
2021-07-05 Move LasS0_FET over, update readme with new version information
    [LasS0-B_Cu.gbl, LasS0-B_Mask.gbs, LasS0-B_Paste.gbp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]
2021-07-05 Add highly unfinished version of AVR pcb and code
    [LasS0-B_Cu.gbl, LasS0-B_Mask.gbs, LasS0-B_Paste.gbp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]
2021-07-07 Update AVR schematic for initial test
    [LasS0.kicad_sch]
2021-07-07 Add fuses to platformio.ini
2021-07-08 Add temporary schematic for AVR version prototype
2021-07-08 Change fuses, remove div 8 prescaler from clock
2021-07-09 Add list to track code optimizations
2021-07-09 Remove Arduino includes, missing ISR for millis still
    [main.cpp]
2021-07-09 Restructure code to use timer compares instead of millis
2021-07-09 [Schematic] Update component fields and add decoupling cap
    [LasS0.kicad_sch]
2021-07-09 [PCB] Implement AVR on PCB
    [LasS0.kicad_pcb, LasS0.kicad_sch]
2021-07-10 [Firmware] Remove timer for debugging, only test input
2021-07-10 [FW] fix code, working now
    [main.cpp]
2021-07-10 Update schematic
    [LasS0.kicad_sch]
2021-07-10 [PCB] Update KiCAD version
    [LasS0.kicad_pcb, LasS0.kicad_sch]
2021-07-10 [PCB] Minor silkscreen updates
    [LasS0.kicad_pcb]
2021-07-10 [PCB] Move a via out of silk
    [LasS0.kicad_pcb]
2021-07-10 [PCB] Create and order fabrication files
    [BOM.csv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]
2021-07-21 [PCB] update silkscreen documentation, changing GitHub to GitLab
    [LasS0.kicad_pcb]
2021-07-21 [FW] Fix fusebits, remove CKDIV8
2021-07-21 [3D] Add cutouts to lower shell for new pin headers
    [LasS0-Lower.stl, LasS0.FCStd]
2021-07-21 Update repo to adhere to template
    [BOM.csv, EMH_eHZ_readhead-PartBody.stl, EMH_eHZ_readhead.FCStd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]
2021-07-22 Fix platformio build issue with folder name
    [main.cpp]
2021-08-07 [Doc] Add schematic to readme
2021-08-09 Update folder structure to fit thingideploy
    [EMH_eHZ_readhead-PartBody.stl, EMH_eHZ_readhead.FCStd, LasS0-Lower.stl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]
2021-08-10 [3D] Fix lower.stl - update thingdata manually
    [LasS0-Lower.stl, LasS0.FCStd]
2021-08-10 [CI/CD] Remove stages
2021-10-16 [CICD] Switch from Thingideploy to Threedeploy
